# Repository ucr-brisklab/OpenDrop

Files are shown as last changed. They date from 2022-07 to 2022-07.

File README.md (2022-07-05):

## OpenDrop 

Open Source Digital Microfluidics Bio Lab

### Brisk-lab's v4.0 OpenDrop

### Open Source Digital Microfluidics Bio Lab

OpenDrop is a new design for an open source digital microfludics platform for research purposes. The device uses recent electro-wetting technology to control small droplets of liquids. Potential applications are lab on a chip devices for automating processes of digital biology. How ever the present design should also open the technology to other field and allow experimentation to find new applications. Including the field of art, music, games and education.

For more info on the open source project see:

http://www.gaudi.ch/OpenDrop

### License

OpenDrop, all design files and software are licensed under a GNU GENERAL PUBLIC LICENSE
See license file in the repository.

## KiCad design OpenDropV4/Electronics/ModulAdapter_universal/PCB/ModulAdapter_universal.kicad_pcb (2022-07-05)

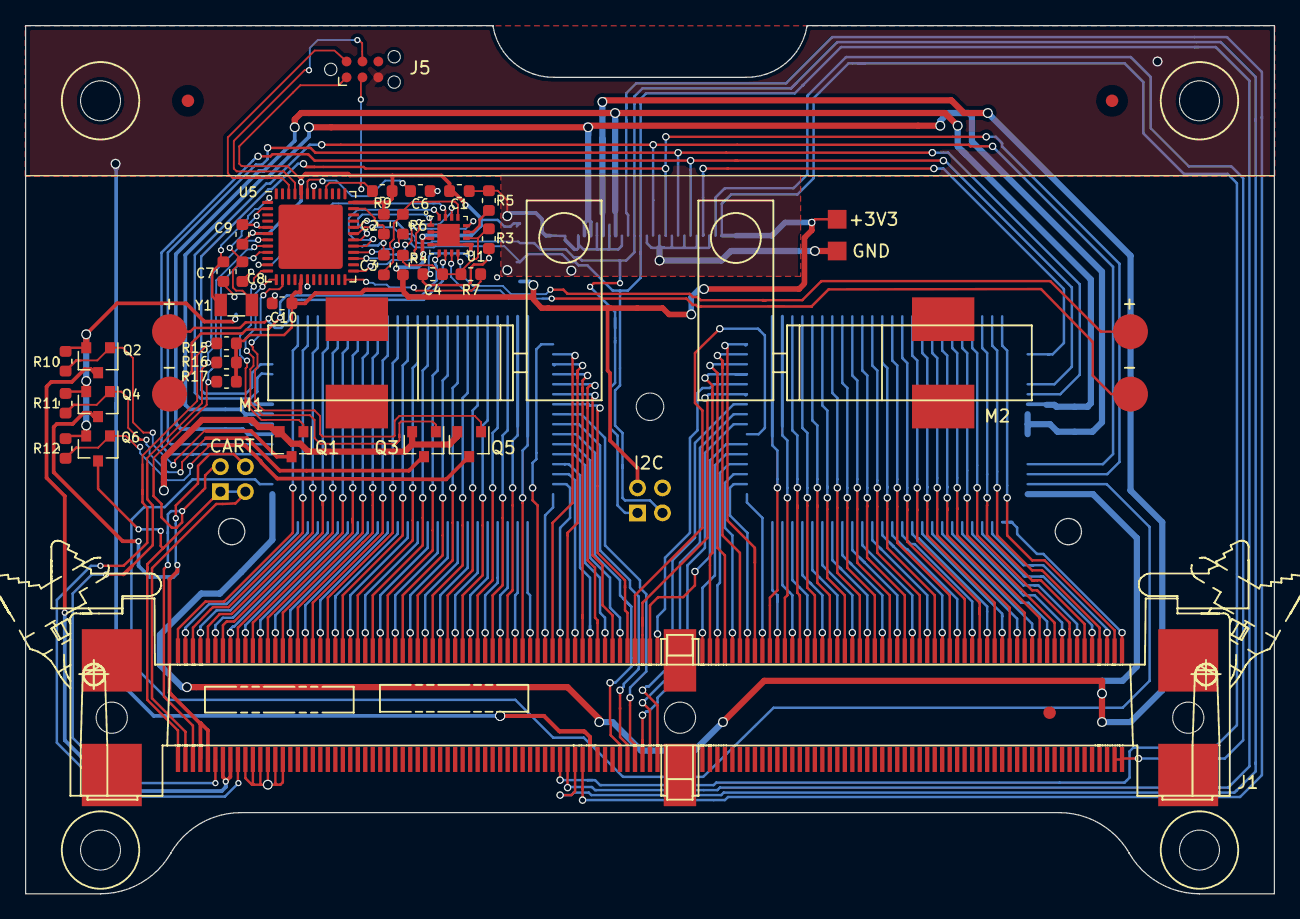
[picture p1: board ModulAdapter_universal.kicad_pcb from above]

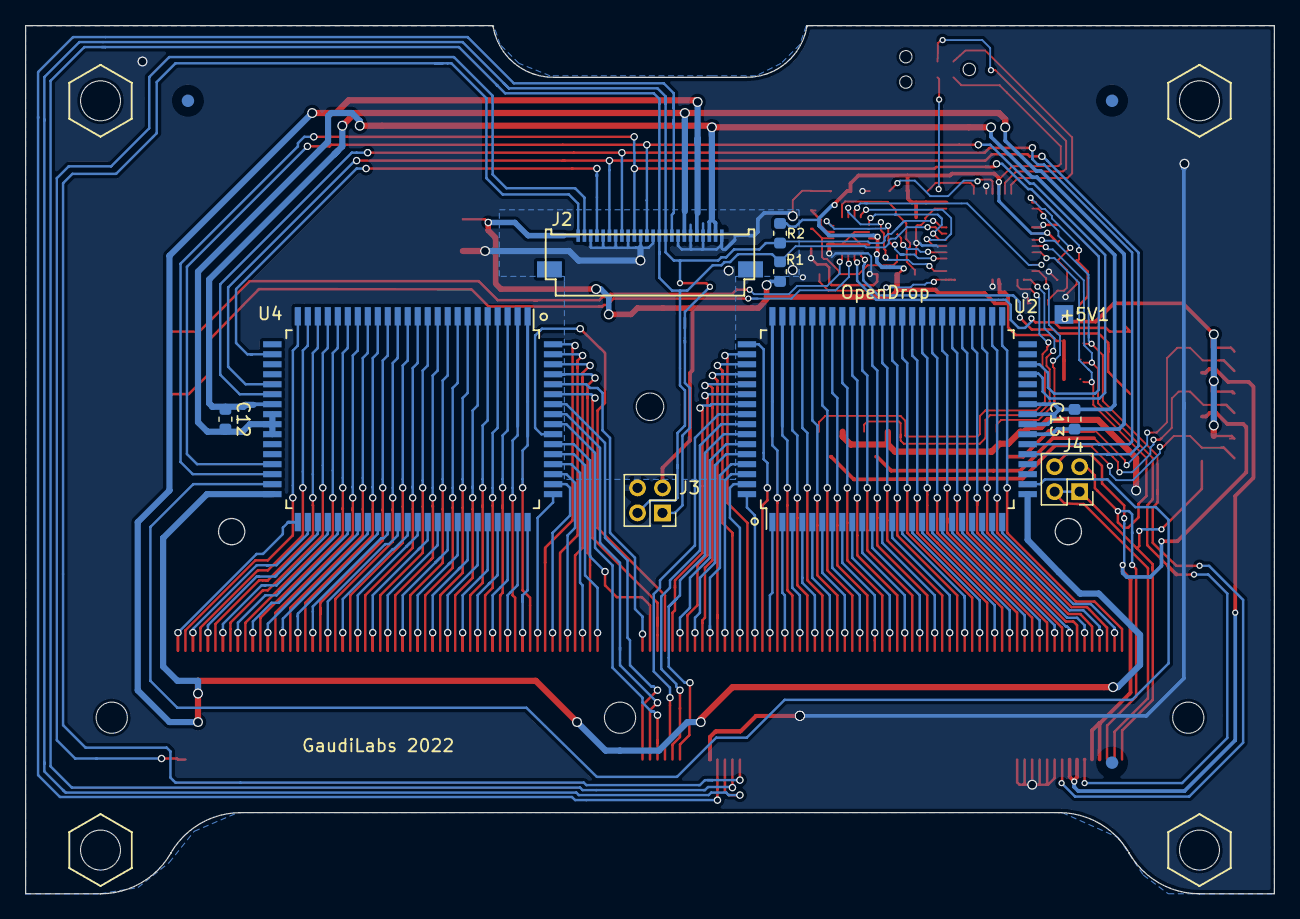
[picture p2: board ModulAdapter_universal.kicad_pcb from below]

Board: 2 copper layers, 100.0 x 69.5 mm, 56 parts (13 on the bottom side), 176 nets.

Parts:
+3V3, +5V1: ScrewPad2; Measurement_Point_Square-SMD-Pad_Small
C1, C4, C9, C10, C12, C13: 100nF; C_0603_1608Metric
C2: 10uF; C_0603_1608Metric
C3: 22nF; C_0603_1608Metric
C6: 1uF; C_0603_1608Metric
C7, C8: 22pF; C_0603_1608Metric
FID1, FID2, FID3, FID4, FID5, FID6: Fiducial; Fiducial_1mm_Dia_2.54mm_Outer_CopperBottom
GND1: ScrewPad2; Measurement_Point_Square-SMD-Pad_Small
H1, H2, H3, H4: MountingHole; MountingHoleM3
J1: Mini_Dimm_244; MiniDimm_06_244_200
J2: Conn_01x24_Female; FFC_MOLEX_EASYON_05mm_24
J3, J4: Conn_02x02_Top_Bottom; PinHeader_2x02_P2.00mm_Vertical
J5: Conn_02x03_Odd_Even; Tag-Connect_TC2030-IDC-NL_2x03_P1.27mm_Vertical
M1: Motor_DC; GreaMotor6mm_Magnet_l
M2: Motor_DC; GreaMotor6mm_Magnet
Q1, Q3, Q5: Q_NMOS_GSD; SOT-23
Q2, Q4, Q6: AO3401A; SOT-23
R1, R2, R9, R10, R11, R12, R15, R16, R17: 10k; R_0603_1608Metric
R3, R7: 4.7k; R_0603_1608Metric
R4: 100k; R_0603_1608Metric
R5: 47k; R_0603_1608Metric
R6: 4.7k (10k); R_0603_1608Metric
U1: TC78H660FTG; P-VQFN16-0303-0.50-001
U2, U4: HV507; PQFP-80_14x20mm_Pitch0.8mm
U5: SAMD21G18B; QFN-48-1EP_7x7mm_P0.5mm_EP5.15x5.15mm
Y1: 32 765; Crystal_SMD_3215-2Pin_3.2x1.5mm

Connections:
+3V3: +3V3.1, C1.1, C2.1, C9.1, C10.1, J1.52, J2.1, J3.3, J5.1, R1.1, R2.1, R4.1, R9.1, R15.1, R16.1, R17.1, U1.3, U5.6, U5.17, U5.36, U5.44
+5V: +5V1.1, Q2.2, Q4.2, Q6.2, R10.1, R11.1, R12.1
BL_C: J2.6, U2.29, U4.29
BOOST: R7.2, U5.24
CLK_C: J2.12, U2.37, U4.37
DIG0: J1.54, J2.15, J3.1, R2.2, U5.32
DIG1: J1.53, J2.14, J3.2, R1.2, U5.31
DI_C: J2.4, U4.26
ENABLE_A: U1.15, U5.11
ENABLE_B: U1.16, U5.29
GND: C1.2, C2.2, C3.2, C4.2, C6.2, C7.1, C8.1, C9.2, C10.2, GND1.1, J1.10, J1.11, J1.12, J1.13, J1.14, J1.15, J1.56, J2.3, J2.5, J2.7, J2.9, J2.11, J2.13, J2.17, J2.19, J2.21, J2.24, J3.4, J5.5, Q1.2, Q3.2, Q5.2, R3.2, R5.2, U1.2, U1.4, U1.9, U1.17, U5.5, U5.18, U5.35, U5.42
GND_C: C12.2, C13.2, J2.22, J2.23, U2.32, U2.33, U2.34, U4.32, U4.33, U4.34
H1: J1.7, J1.8, Q2.3
H3: J1.4, J1.5, J4.4, Q4.3
H5: J1.1, J1.2, J4.1, J4.2, Q6.3
HEATER1: Q1.1, U5.12
HEATER2: Q3.1, U5.13
HEATER3: Q5.1, U5.14
J3: J1.3, J4.3, R17.2, U5.9
LE_C: J2.10, U2.38, U4.38
MODE: R6.2, U5.28
unnamed: C3.1, R6.1, U1.13
unnamed: C4.1, R3.1, R4.2, R7.1, U1.10
unnamed: C6.1, U5.43
unnamed: C7.2, U5.1, Y1.1
unnamed: C8.2, U5.2, Y1.2
unnamed: J1.60, U2.74
unnamed: J1.61, U2.73
unnamed: J1.62, U2.72
unnamed: J1.63, U4.72
unnamed: J1.64, U4.73
unnamed: J1.65, U4.74
unnamed: J1.123, U2.41
unnamed: J1.124, U2.24
unnamed: J1.125, U2.42
unnamed: J1.126, U2.23
unnamed: J1.127, U2.43
unnamed: J1.128, U2.22
unnamed: J1.129, U2.44
unnamed: J1.130, U2.21
unnamed: J1.131, U2.45
unnamed: J1.132, U2.20
unnamed: J1.133, U2.46
unnamed: J1.134, U2.19
unnamed: J1.135, U2.47
unnamed: J1.136, U2.18
unnamed: J1.137, U2.48
unnamed: J1.138, U2.17
unnamed: J1.139, U2.49
unnamed: J1.140, U2.16
unnamed: J1.141, U2.50
unnamed: J1.142, U2.15
unnamed: J1.143, U2.51
unnamed: J1.144, U2.14
unnamed: J1.145, U2.52
unnamed: J1.146, U2.13
unnamed: J1.147, U2.53
unnamed: J1.148, U2.12
unnamed: J1.149, U2.54
unnamed: J1.150, U2.11
unnamed: J1.151, U2.55
unnamed: J1.152, U2.10
unnamed: J1.153, U2.56
unnamed: J1.154, U2.9
unnamed: J1.155, U2.57
unnamed: J1.156, U2.8
unnamed: J1.157, U2.58
unnamed: J1.158, U2.7
unnamed: J1.159, U2.59
unnamed: J1.160, U2.6
unnamed: J1.161, U2.60
unnamed: J1.162, U2.5
unnamed: J1.163, U2.61
unnamed: J1.164, U2.4
unnamed: J1.165, U2.62
unnamed: J1.166, U2.3
unnamed: J1.167, U2.63
unnamed: J1.168, U2.2
unnamed: J1.169, U2.64
unnamed: J1.170, U2.1
unnamed: J1.171, U2.65
unnamed: J1.172, U2.80
unnamed: J1.173, U2.66
unnamed: J1.174, U2.79
unnamed: J1.175, U2.67
unnamed: J1.176, U2.78
unnamed: J1.177, U2.68
unnamed: J1.178, U2.77
unnamed: J1.179, U2.69
unnamed: J1.180, U2.76
unnamed: J1.181, U2.70
unnamed: J1.182, U2.75
unnamed: J1.183, U2.71
unnamed: J1.184, U4.71
unnamed: J1.185, U4.75
unnamed: J1.186, U4.70
unnamed: J1.187, U4.76
unnamed: J1.188, U4.69
unnamed: J1.189, U4.77
unnamed: J1.190, U4.68
unnamed: J1.191, U4.78
unnamed: J1.192, U4.67
unnamed: J1.193, U4.79
unnamed: J1.194, U4.66
unnamed: J1.195, U4.80
unnamed: J1.196, U4.65
unnamed: J1.197, U4.1
unnamed: J1.198, U4.64
unnamed: J1.199, U4.2
unnamed: J1.200, U4.63
unnamed: J1.201, U4.3
unnamed: J1.202, U4.62
unnamed: J1.203, U4.4
unnamed: J1.204, U4.61
unnamed: J1.205, U4.5
unnamed: J1.206, U4.60
unnamed: J1.207, U4.6
unnamed: J1.208, U4.59
unnamed: J1.209, U4.7
unnamed: J1.210, U4.58
unnamed: J1.211, U4.8
unnamed: J1.212, U4.57
unnamed: J1.213, U4.9
unnamed: J1.214, U4.56
unnamed: J1.215, U4.10
unnamed: J1.216, U4.55
unnamed: J1.217, U4.11
unnamed: J1.218, U4.54
unnamed: J1.219, U4.12
unnamed: J1.220, U4.53
unnamed: J1.221, U4.13
unnamed: J1.222, U4.52
unnamed: J1.223, U4.14
unnamed: J1.224, U4.51
unnamed: J1.225, U4.15
unnamed: J1.226, U4.50
unnamed: J1.227, U4.16
unnamed: J1.228, U4.49
unnamed: J1.229, U4.17
unnamed: J1.230, U4.48
unnamed: J1.231, U4.18
unnamed: J1.232, U4.47
unnamed: J1.233, U4.19
unnamed: J1.234, U4.46
unnamed: J1.235, U4.20
unnamed: J1.236, U4.45
unnamed: J1.237, U4.21
unnamed: J1.238, U4.44
unnamed: J1.239, U4.22
unnamed: J1.240, U4.43
unnamed: J1.241, U4.23
unnamed: J1.242, U4.42
unnamed: J1.243, U4.24
unnamed: J1.244, U4.41
unnamed: M1.1, U1.5
unnamed: M1.2, U1.6
unnamed: M2.1, U1.8
unnamed: M2.2, U1.7
unnamed: Q1.3, Q2.1, R10.2
unnamed: Q3.3, Q4.1, R11.2
unnamed: Q5.3, Q6.1, R12.2
unnamed: R5.1, U1.11
unnamed: U2.26, U4.39
PHASE_A: U1.1, U5.30
PHASE_B: U1.14, U5.25
POL_C: J2.8, U2.30, U4.30
RESET: J5.3, R9.2, U5.40
SENS_PAD: J1.55, J2.16
STBY: U1.12, U5.27
SWCLK: J5.4, U5.45
SWDIO: J5.2, U5.46
TH1: J1.9, R15.2, U5.7
TH2: J1.6, R16.2, U5.8
VDD_C: C12.1, C13.1, J2.18, U2.31, U4.31
V_GND: J1.121, J1.122, J2.2
V_HV_C: J2.20, U2.25, U4.40

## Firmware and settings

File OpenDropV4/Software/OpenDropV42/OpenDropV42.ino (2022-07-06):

/*
  Basic Code to run the OpenDrop V4.1, Research platfrom for digital microfluidics
  Object codes are defined in the OpenDrop.h library
  Written by Urs Gaudenz from GaudiLabs, 2021
*/

#include <SPI.h>
#include <Wire.h>

#include <Adafruit_GFX.h>
#include <Adafruit_SSD1306.h>

#include <OpenDrop.h>
#include <OpenDropAudio.h>

#include <hardware_def.h>


OpenDrop OpenDropDevice = OpenDrop();
Drop *myDrop = OpenDropDevice.getDrop();


bool FluxCom[16][8];
bool FluxBack[16][8];

int ControlBytesIn[16];
int ControlBytesOut[24];
int readbyte;
int writebyte;

int JOY_value;
int joy_x, joy_y;
int x, y;
int del_counter = 0;
int del_counter2 = 0;

bool SWITCH_state = true;
bool SWITCH_state2 = true;
bool idle = true;

bool Magnet1_state = false;
bool Magnet2_state = false;

int j = 0;

// the setup function runs once when you press reset or power the board
void setup() {
  Serial.begin(115200);
  OpenDropDevice.begin(nullptr);

  ControlBytesOut[23] = OpenDropDevice.get_ID();
  Serial.println(OpenDropDevice.get_ID());
  // OpenDropDevice.set_voltage(240,false,1000);

  OpenDropDevice.set_Fluxels(FluxCom);  // fluidic pixel

  pinMode(JOY_pin, INPUT);

  OpenDropAudio.begin(16000);
  OpenDropAudio.playMe(2);
  delay (2000);

  OpenDropDevice.drive_Fluxels();
  OpenDropDevice.update_Display();
  Serial.println("Welcome to OpenDrop");

  myDrop->begin(7, 4);
  OpenDropDevice.update();

  del_counter = millis();

}


void loop() {
  if (Serial.available() > 0)           //receive data from App
  {
    readbyte = Serial.read();
    if (x < FluxlPad_width)
      for (y = 0; y < 8; y++) FluxCom[x][y] = (((readbyte) >> (y)) & 0x01);
    else ControlBytesIn[x - FluxlPad_width] = readbyte;

    x++;
    digitalWrite(LED_Rx_pin, HIGH);
    if (x == (FluxlPad_width + 16))
    { OpenDropDevice.set_Fluxels(FluxCom);
      OpenDropDevice.drive_Fluxels();
      OpenDropDevice.update_Display();

      if ((ControlBytesIn[0] & 0x2) && (Magnet1_state == false)) {
        Magnet1_state = true;
        OpenDropDevice.set_Magnet(0, HIGH);
      };

      if (!(ControlBytesIn[0] & 0x2) && (Magnet1_state == true)) {
        Magnet1_state = false;
        OpenDropDevice.set_Magnet(0, LOW);
      } ;

      if ((ControlBytesIn[0] & 0x1) && (Magnet2_state == false)) {
        Magnet2_state = true;
        OpenDropDevice.set_Magnet(1, HIGH);
      };

      if (!(ControlBytesIn[0] & 0x1) && (Magnet2_state == true)) {
        Magnet2_state = false;
        OpenDropDevice.set_Magnet(1, LOW);
      } ;

      for (int x = 0; x < (FluxlPad_width) ; x++)
      { writebyte = 0;
        for (int y = 0; y < FluxlPad_heigth ; y++)
          writebyte = (writebyte << 1) + (int)OpenDropDevice.get_Fluxel(x, y);
        ControlBytesOut[x] = writebyte;
      }

      OpenDropDevice.set_Temp_1(ControlBytesIn[10]);
      OpenDropDevice.set_Temp_2(ControlBytesIn[11]);
      OpenDropDevice.set_Temp_3(ControlBytesIn[12]);

      OpenDropDevice.show_feedback(ControlBytesIn[8]);

      ControlBytesOut[17] = OpenDropDevice.get_Temp_L_1();
      ControlBytesOut[18] = OpenDropDevice.get_Temp_H_1();
      ControlBytesOut[19] = OpenDropDevice.get_Temp_L_2();
      ControlBytesOut[20] = OpenDropDevice.get_Temp_H_2();
      ControlBytesOut[21] = OpenDropDevice.get_Temp_L_3();
      ControlBytesOut[22] = OpenDropDevice.get_Temp_H_3();

      for (x = 0; x < 24; x++) Serial.write(ControlBytesOut[x]);
      x = 0;
    };
  }
  else digitalWrite(LED_Rx_pin, LOW);
  del_counter--;

  if (millis() - del_counter > 2000) {             //update Display
    OpenDropDevice.update_Display();
    del_counter = millis();
  }

  SWITCH_state = digitalRead(SW1_pin);
  SWITCH_state2 = digitalRead(SW2_pin);

  if (!SWITCH_state)                    //activate Menu
  {
    OpenDropAudio.playMe(1);
    Menu(OpenDropDevice);
    OpenDropDevice.update_Display();
    del_counter2 = 200;
  }


  if (!SWITCH_state2)                    //activate Reservoirs
  {
    if ((myDrop->position_x() == 15) && (myDrop->position_y() == 3))
    {
      myDrop->begin(14, 1);
      OpenDropDevice.dispense(1, 1200);
    }
    if ((myDrop->position_x() == 15) && (myDrop->position_y() == 4))
    {
      myDrop->begin(14, 6);
      OpenDropDevice.dispense(2, 1200);
    }

    if ((myDrop->position_x() == 0) && (myDrop->position_y() == 3))
    {
      myDrop->begin(1, 1);
      OpenDropDevice.dispense(3, 1200);
    }
    if ((myDrop->position_x() == 0) && (myDrop->position_y() == 4))
    {
      myDrop->begin(1, 6);
      OpenDropDevice.dispense(4, 1200);
    }

    if ((myDrop->position_x() == 10) && (myDrop->position_y() == 2))
    { if (Magnet1_state) {
        OpenDropDevice.set_Magnet(0, LOW);
        Magnet1_state = false;
      }
      else {
        OpenDropDevice.set_Magnet(0, HIGH);
        Magnet1_state = true;
      }
      while (!digitalRead(SW2_pin));
    }

    if ((myDrop->position_x() == 5) && (myDrop->position_y() == 2))
    {
      if (Magnet2_state) {
        OpenDropDevice.set_Magnet(1, LOW);
        Magnet2_state = false;
      }
      else {
        OpenDropDevice.set_Magnet(1, HIGH);
        Magnet2_state = true;
      }
      while (!digitalRead(SW2_pin));
    }

  }


  JOY_value = analogRead(JOY_pin);      //navigate using Joystick

  if ((JOY_value < 950) & (del_counter2 == 0))
  {
    if  (JOY_value < 256)
    {
      myDrop->move_right();
    }

    if  ((JOY_value > 725) && (JOY_value < 895))
    {
      myDrop->move_up();
    }

    if  ((JOY_value > 597) && (JOY_value < 725))
    {
      myDrop->move_left();
    }

    if  ((JOY_value > 256) && (JOY_value < 597))
    {
      myDrop->move_down();
    }

    OpenDropDevice.update_Drops();
    OpenDropDevice.update();
    if (idle) {
      del_counter2 = 1800;
      idle = false;
    } else del_counter2 = 400;

  }

  if (JOY_value > 950) {
    del_counter2 = 0;
    idle = true;
  }
  if (del_counter2 > 0) del_counter2--;

} // main loop

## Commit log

2022-07-05 getting our OpenDropv4 ready for refactor - removing deprecated (<v4) files
    [Cardridge_PCB.dxf, ModulAdapter_universal.kicad_pcb, ModulAdapter_universal.sch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]
2022-07-06 getting magnet module 4.1 to work with our 4.0 opendrop
2022-07-06 soft i2c library added for controlling 4.1 magnet with 4.0 opendrop
